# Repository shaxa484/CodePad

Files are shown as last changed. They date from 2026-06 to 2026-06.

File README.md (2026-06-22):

# CodePad

CodePad is a 6 key macropad with a rotary encoder, and an OLED Display made for helping me while coding. It uses QMK firmware.

## Features:
- Dual layer plastic case. 
- 128x32 OLED Display
- EC11 Rotary encoder for whatever you want(volume control, scrolling)
- 6 Keys

## CAD Model:
Everything fits together using 4 M3 Bolts and heatset inserts. 4 for the each corner of the case. 

It has 2 separate printed pieces. The base where the PCB sits, and the top cover.

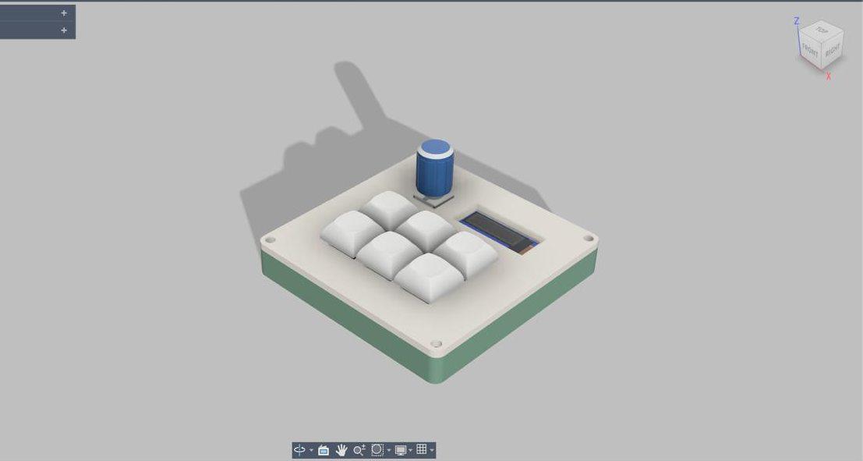
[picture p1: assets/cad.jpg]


Made in Fusion360.

## PCB
Here's my PCB! It was made in KiCad.

Schematic
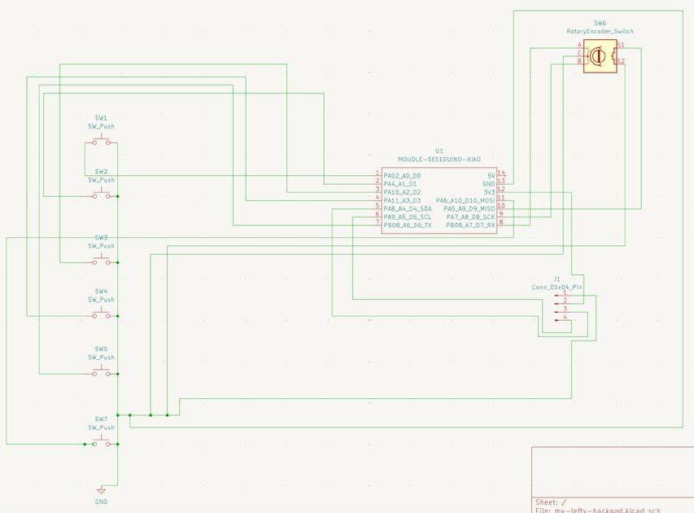
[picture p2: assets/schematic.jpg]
Schematic


PCB
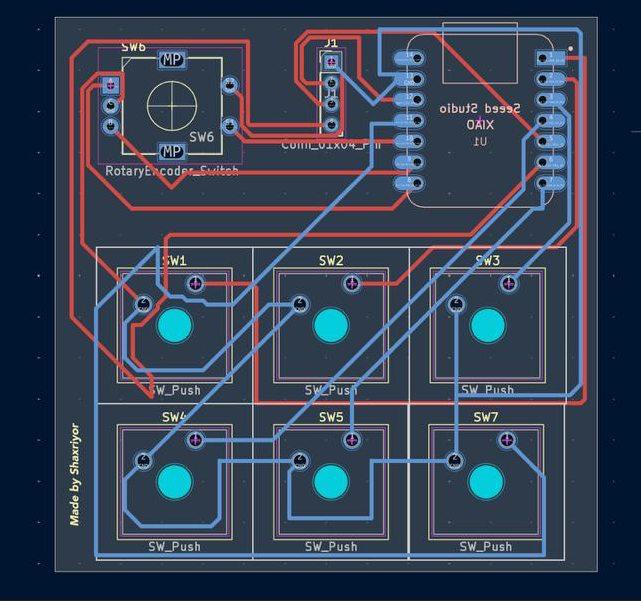
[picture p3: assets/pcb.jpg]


I didn't use any matrixes cause easier the better no need to make it complex.

## Firmware Overview
This hackpad uses [QMK](https://qmk.fm/) firmware for everything. 

- the rotary encoder changes volume. press to mute
- The 6 keys currently as copy, paste, shift select, pause and play, keyboard brightness up and down I'm planning to change it later.
- The OLED is would have a clock but I'm searching for more creative ideas for it

## BOM:
Here is everything needed to make this hackpad

- 6x Cherry MX Switches
- 6x DSA Keycaps
- 4x M3x5x4 Heatset inserts
- 4x M3x16mm SHCS Bolts
- 1x 0.91" 128x32 OLED Display
- 1x EC11 Rotary Encoder
- 1x XIAO RP2040
- 1x Case (2 printed parts)

## Extra stuff

Fun fact: I completed building it a day before my 19th birthday

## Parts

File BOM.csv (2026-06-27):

BOM
Item # | Component | Description | Quantity | Unit Price ($) | Total Price ($) | Notes / Suggested Source
1 | Cherry MX Switches (10-pack) | Mechanical keyboard switches (Linear/Tactile/Clicky) | 1 | 8.0 | 8.0 | Retail pricing from keyboard vendors.
2 | DSA Keycaps (10-pack) | Blank DSA profile PBT/ABS keycaps | 1 | 6.0 | 6.0 | Standard blank 10-pack from Amazon/AliExpress.
3 | M3x5x4 Heatset Inserts | Brass threaded inserts for plastic 3D prints (Pack of 10) | 1 | 2 | 2 | Hobbyist packs on Amazon or electronics vendors.
4 | M3x16mm SHCS Bolts | Socket Head Cap Screws for casing fastening (Pack of 10) | 1 | 2 | 2 | Hardware store or electronic hardware kits.
5 | 0.91" 128x32 OLED Display | SSD1306 I2C monochrome graphic OLED screen module | 1 | 4.5 | 4.5 | Standard I2C display module from Amazon/Adafruit/AliExpress.
6 | EC11 Rotary Encoder | 20-detent rotary encoder with integrated push-switch | 1 | 3.0 | 3.0 | Electronics component supplier.
7 | Aluminum Encoder Knob | Knob to fit 6mm D-shaft or knurled shaft EC11 encoder | 1 | 2.5 | 2.5 | Highly recommended addition for usability.
8 | XIAO RP2040 | Seeed Studio XIAO development board with RP2040 chip | 1 | 7.5 | 7.5 | Official Seeed Studio distributors or premium hobby shops.
9 | 3D Printed Case (2 Parts) | Top and bottom enclosure shells fabricated via 3D printing | 1 | 15.0 | 15.0 | JLCPCB 3D Printing Service (SLA/Resin or Nylon SLS).
 | TOTAL ESTIMATE |  |  |  | 50.5 | Excludes potential shipping and local taxes.

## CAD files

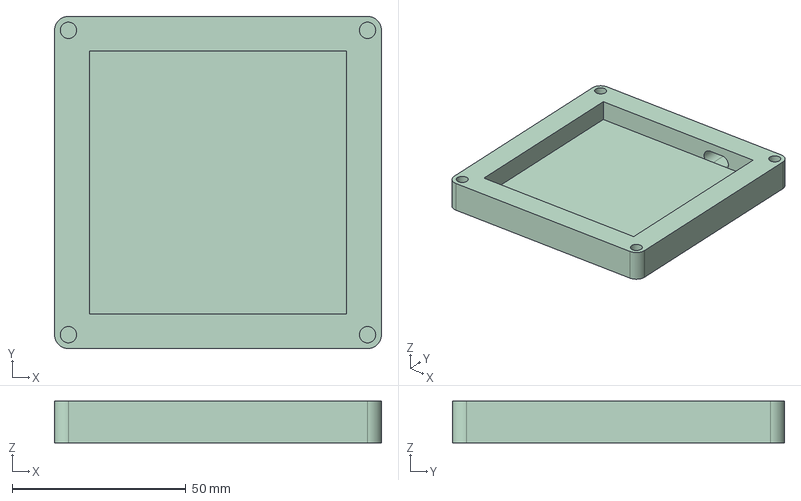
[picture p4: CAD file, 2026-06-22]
Production/Bottom.step
94.0 x 95.5 x 12.0 mm

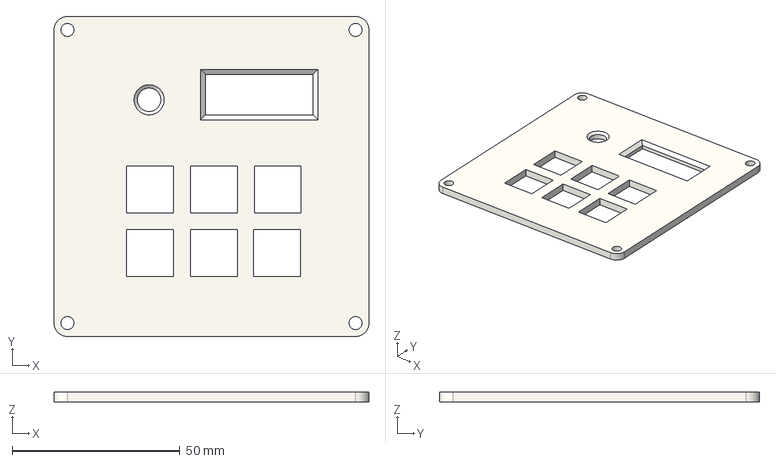
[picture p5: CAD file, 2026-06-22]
Production/Top.step
94.0 x 95.5 x 3.00 mm

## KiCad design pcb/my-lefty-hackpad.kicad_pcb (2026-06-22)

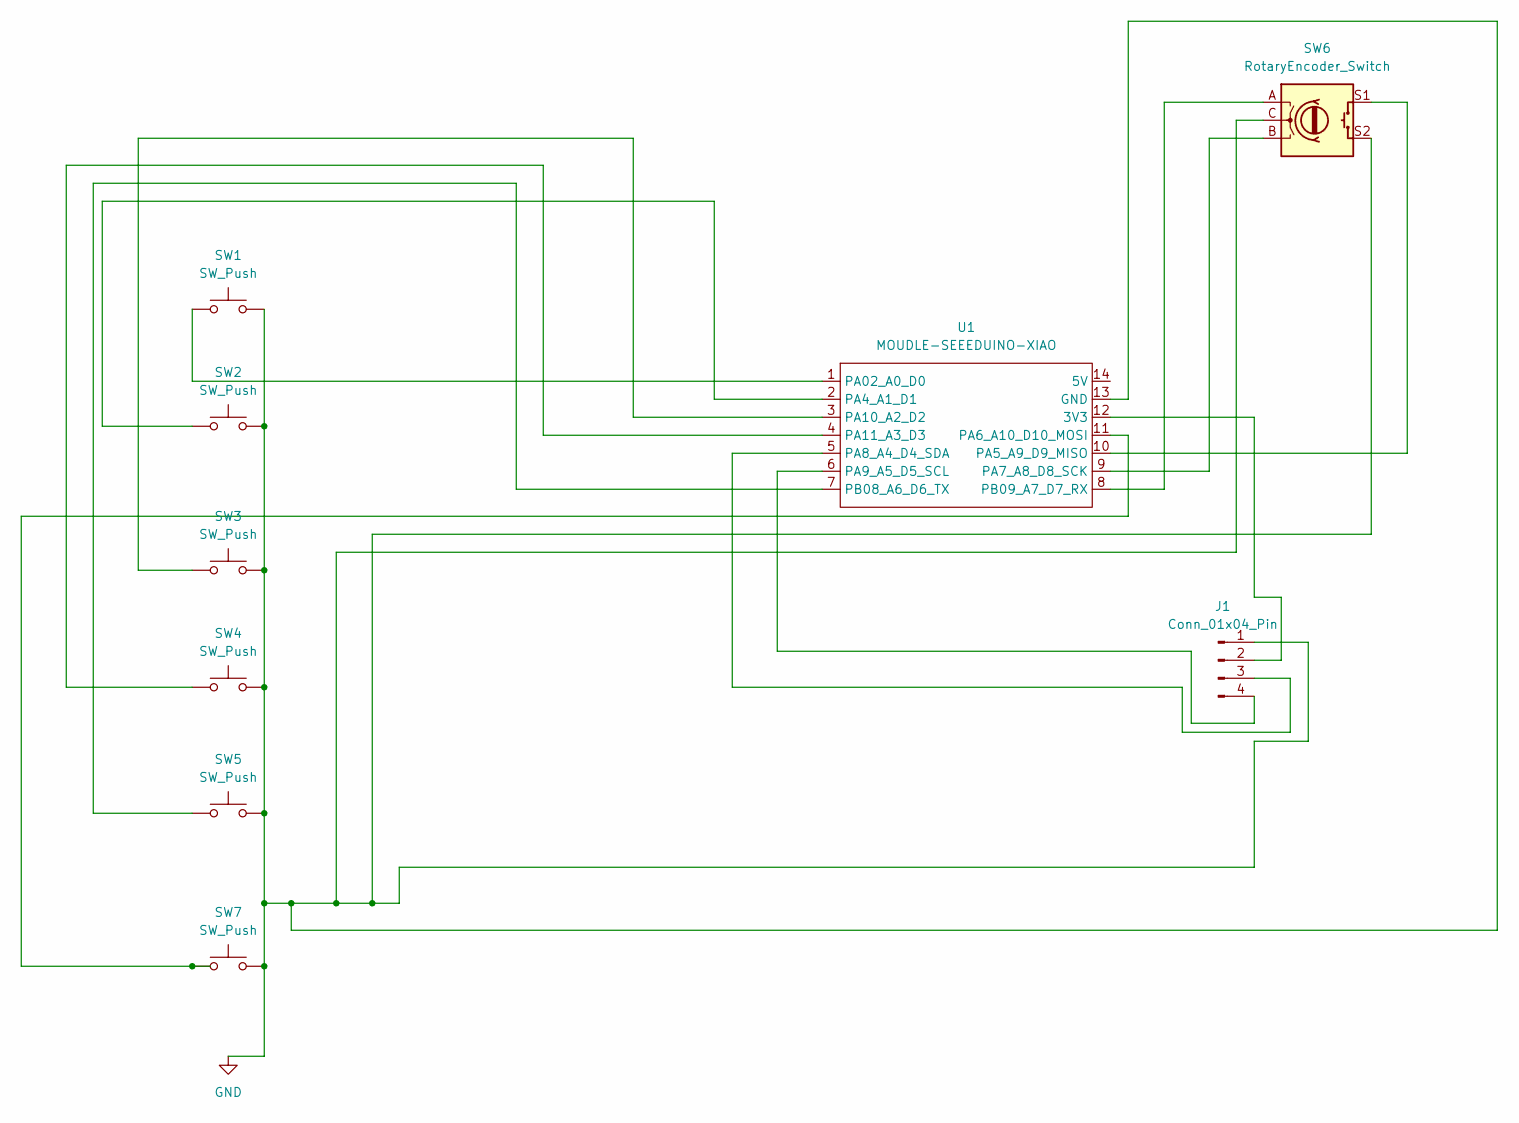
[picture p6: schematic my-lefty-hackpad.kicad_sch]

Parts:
J1: Conn_01x04_Pin; PinHeader_1x04_P2.54mm_Vertical
SW1, SW2, SW3, SW4, SW5, SW7: SW_Push; SW_Cherry_MX_1.00u_Plate
SW6: RotaryEncoder_Switch; RotaryEncoder_Alps_EC11E-Switch_Vertical_H20mm
U1: MOUDLE-SEEEDUINO-XIAO; XIAO-Generic-Hybrid-14P-2.54-21X17.8MM

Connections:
GND: J1.1, SW1.2, SW2.2, SW3.2, SW4.2, SW5.2, SW6.C, SW6.S2, SW7.2, U1.13 (GND)
unnamed: J1.2, U1.12 (3V3)
unnamed: J1.3, U1.5 (PA8_A4_D4_SDA)
unnamed: J1.4, U1.6 (PA9_A5_D5_SCL)
unnamed: SW1.1, U1.1 (PA02_A0_D0)
unnamed: SW2.1, U1.2 (PA4_A1_D1)
unnamed: SW6.S1, U1.10 (PA5_A9_D9_MISO)
unnamed: SW7.1, U1.11 (PA6_A10_D10_MOSI)
unnamed: SW6.B, U1.9 (PA7_A8_D8_SCK)
unnamed: SW3.1, U1.3 (PA10_A2_D2)
unnamed: SW4.1, U1.4 (PA11_A3_D3)
unnamed: SW5.1, U1.7 (PB08_A6_D6_TX)
unnamed: SW6.A, U1.8 (PB09_A7_D7_RX)

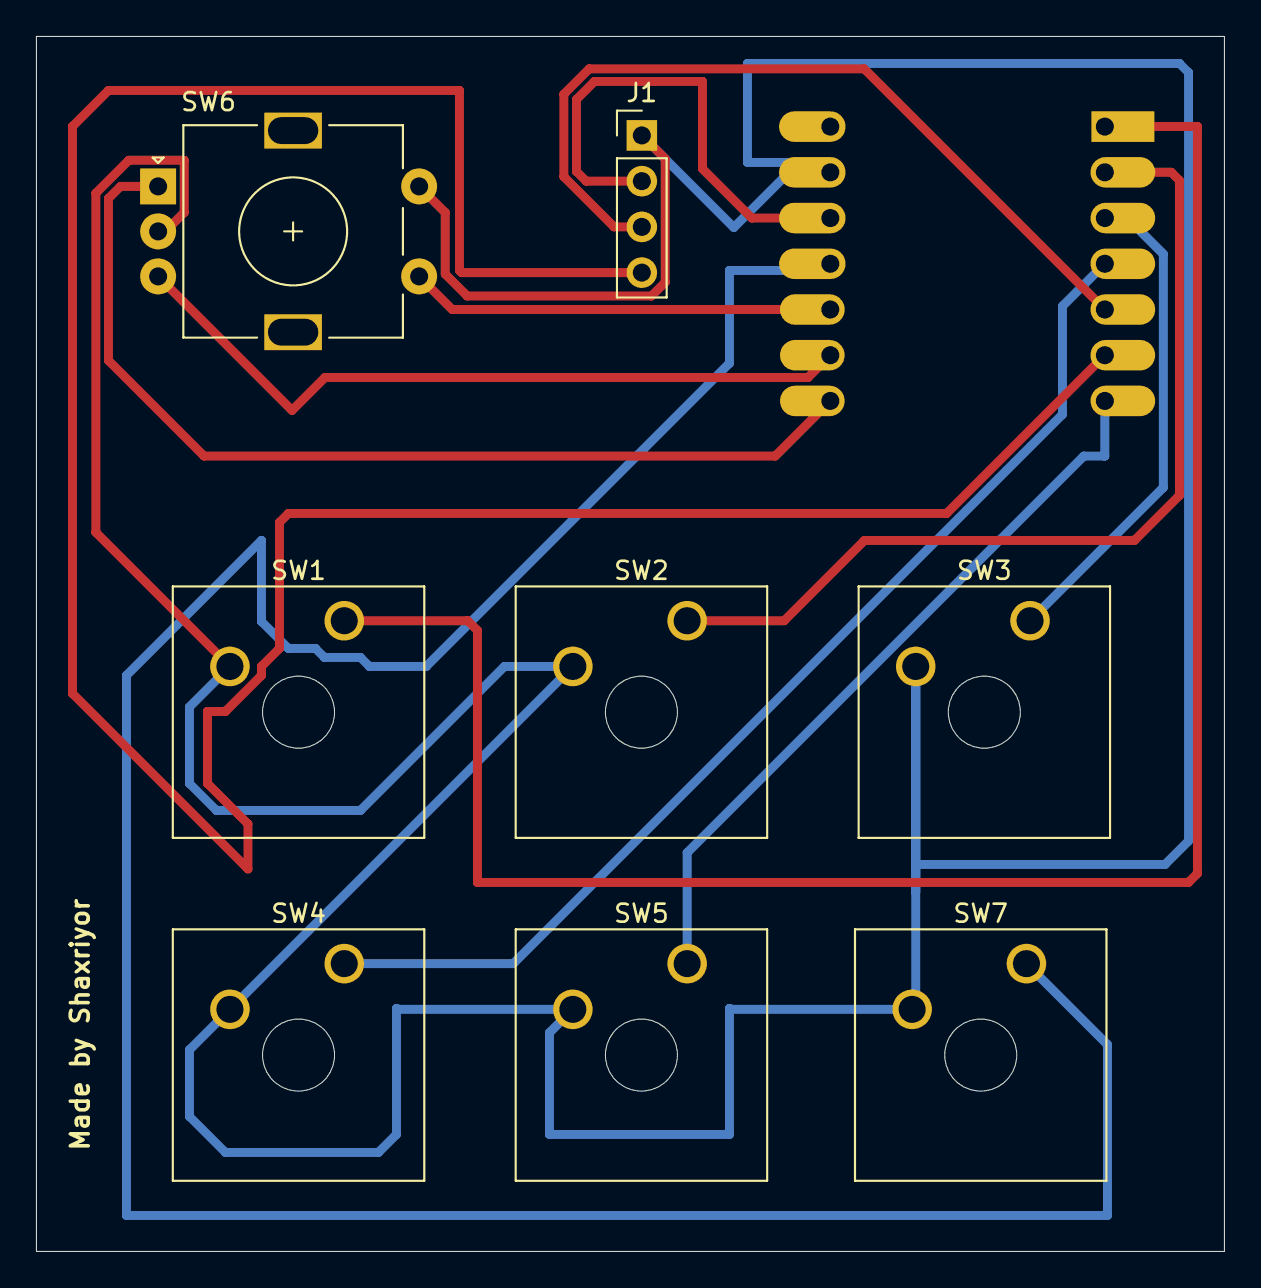
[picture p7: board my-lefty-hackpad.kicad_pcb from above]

Board: 2 copper layers, 66.0 x 67.5 mm, 9 parts (1 on the bottom side), 13 nets.

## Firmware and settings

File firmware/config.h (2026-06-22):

#define MANUFACTURER    Shaxriyor
#define PRODUCT         CodePad

#define DIRECT_PINS { \
    { D0, D1, D2 }, \
    { D3, D4, D5 }  \
}

#define ENCODERS_PAD_A { D6 }
#define ENCODERS_PAD_B { D7 }
#define ENCODER_RESOLUTION 4

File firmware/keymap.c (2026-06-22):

#include QMK_KEYBOARD_H

enum custom_layers {
    _BASE
};

const uint16_t PROGMEM keymaps[][MATRIX_ROWS][MATRIX_COLS] = {
    [_BASE] = LAYOUT(
        S(KC_RGHT), KC_MPLY, KC_MFFD,
        LGUI(KC_C), LGUI(KC_V), KC_MUTE  
    )
};

#ifdef ENCODER_MAP_ENABLE

const uint16_t PROGMEM encoder_map[][NUM_ENCODERS][NUM_DIRECTIONS] = {
    [_BASE] = { ENCODER_DIRECTION_MAP(KC_VOLD, KC_VOLU) }
};
#endif

#ifdef OLED_ENABLE
bool oled_task_user(void) {
    oled_write_ln("  CodePad Mac ", false);
    oled_write_ln("--------------", false);
    uint32_t total_seconds = timer_read32() / 1000;
    uint32_t minutes = total_seconds / 60;
    uint32_t seconds = total_seconds % 60;
    
    char clock_str[16];
    snprintf(clock_str, sizeof(clock_str), "Uptime: %02lu:%02lu", minutes, seconds);
    oled_write_ln(clock_str, false);
    
    return false;
}
#endif

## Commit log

2026-06-22 Gerbers files
2026-06-22 pcb and schematic pictures
2026-06-22 Add initial hardware driver configuration
2026-06-22 Create README.md for CodePad project
    Added detailed README for CodePad project including features, CAD model, PCB details, firmware overview, BOM, and extra information.
2026-06-22 Update README
    Removed mention of silkscreen import from Figma.
2026-06-22 update on pcb
2026-06-22 Update info.json to modify features
    Removed diode_direction and added encoder configuration.
2026-06-22 Update button layout in info.json
